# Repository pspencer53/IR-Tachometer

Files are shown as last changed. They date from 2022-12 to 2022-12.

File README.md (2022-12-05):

# IR-Tachometer
This is my learning experience building a very low cost tachometer that I wanted to build to measure the RPM of the spindles of the various CNC Routers that I have been using. 
## Hardware 
- Arduino Mini-Pro ( under $4.00 at [AliExpress](https://www.aliexpress.com/item/32821902128.html) )
These are now obsolete, but any arduino will do.  I just happen to have a few of these
- OLED Display ($3.50 at [AliEpress](https://www.aliexpress.com/item/32920071528.html) (Uses Adafuit SSD1306 library) 
- Infrared Sensor ($2.00 at [AliExpress](https://www.aliexpress.com/item/32952079917.html) ( 3pin IR Infrared barrier Module obstacle avoidance sensor) 
- Lithium Battery Charger Module ($1.00 at [Aliexpress](https://www.aliexpress.com/item/32986135934.html) )
- battery 3.7v 450mAh or so. ($3.65 at [AliExpress](https://www.aliexpress.com/item/4000908332181.html) )
## Design
There are several ways to do this.  I am testing all 3.
1. Count pulses for a period of time using a loop.  This is way too sketchy and was only used as a reference ( [See this article](https://how2electronics.com/digital-tachometer-ir-sensor-arduino/) )
2. Use interupts and measure the time between pulses.  My first attempt at this was less than satsfying.   I added a running average function to smooth out the jitters and it now works pretty well..
3. Use interrupt to time a window and measure how many pulses occur during this window of time, such as 500msec or 1 sec. [See Blinky with Timer1 OVF](https://blog.podkalicki.com/arduino-blinky-with-timer1-ovf/)
4. Use a Frequency Count library such as from [PJRC for the Teensy](https://www.pjrc.com/teensy/td_libs_FreqCount.html)

## Final Code
I implemented option 2, which handles lower RPM's pretty well.  
Essentially, the program sets up an interrupt to trip every time there is a pulse on the sensor, and measures the time since the last pules.  
The RPM is calculated using the width of the pulse.  A 1 Second pulse as an example would be 60 RPM.   10mSec would be 6000 RPM. 

I also implemented a "No Pulses detected" and "Too Close" based on the sensor being either always on or always off.  

The correct operation is when the LED on the sensor is flickering.  

## Help
 - [Github-flavored Markdown info page.](http://github.github.com/github-flavored-markdown/)
 - [Mermaid diagrams](https://mermaid-js.github.io/mermaid/#/)

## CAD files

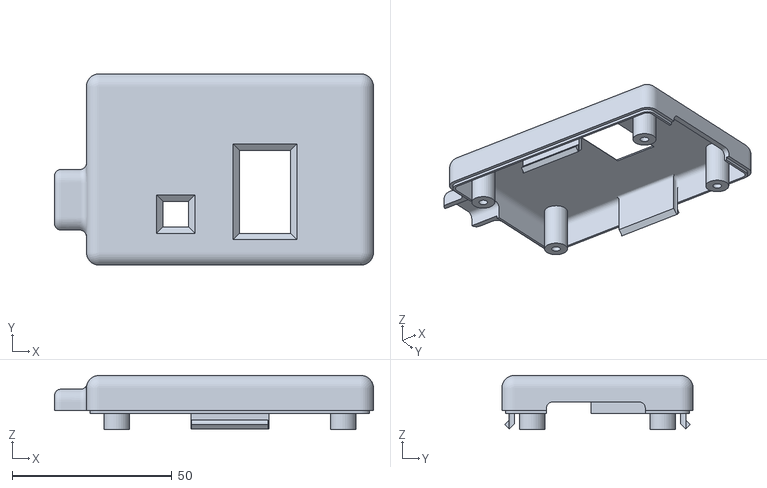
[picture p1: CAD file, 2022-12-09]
Case_Top.stl
100.0 x 60.0 x 17.0

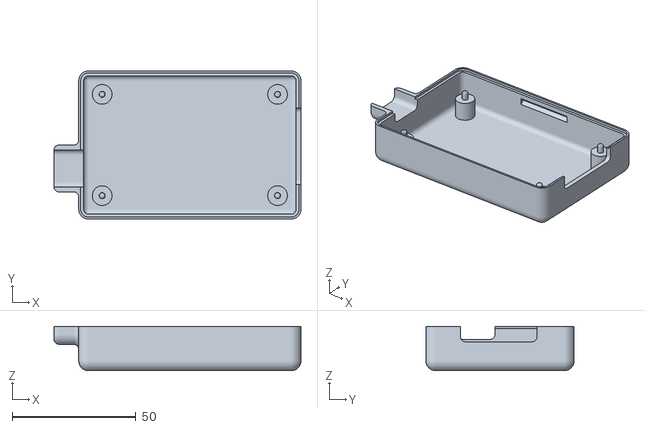
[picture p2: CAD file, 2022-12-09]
Case_Bottom.stl
100.0 x 60.0 x 18.0

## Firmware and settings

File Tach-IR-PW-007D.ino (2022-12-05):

/*********
  12/09/2021: PDS - Configure Tachometer by picking items from DIY Tach script
  12/30/2021: PDS - Updated to use Sensor as a select switch.  Hold finger over sensor while powering on triggers a debug menu. 
                  - Also, turn off Serial unless a menu (above) has been triggered. 
  12/01/2022: PDS - Version 7C.  Uses pulse width.  Can handle very slow pulses as well as fast.
                  - Added setTextColor(WHITE,BLACK) instead if just WHITE
                  - Added a "erase a rectangle" to clear old messages below readings
                  - *DONE* TODO: Verify that the tach is calculating correctly (x/factor?)
                  - Add an averaging function to smooth out the RPM jumping around. 
                     ( https://www.aranacorp.com/en/implementation-of-the-moving-average-in-arduino/ )
                    Added a *RAW* debug line below the smooth RPM text
                  - It is a wrap.
*********/

#include <SPI.h>
#include <Wire.h>
#include <Adafruit_GFX.h>
#include <Adafruit_SSD1306.h>

#define SCREEN_WIDTH 128 // OLED display width, in pixels
#define SCREEN_HEIGHT 64 // OLED display height, in pixels
#define SENSORPIN 2 // Sensor IO Pin

// Declaration for an SSD1306 display connected to I2C (SDA, SCL pins)
#define OLED_RESET     -1 // Reset pin # (or -1 if sharing Arduino reset pin)
Adafruit_SSD1306 display(SCREEN_WIDTH, SCREEN_HEIGHT, &Wire, OLED_RESET);

// Define Variables
char strCodeName[] = "Tach-OLED";
char strCodeVersion[] = "7.3";
unsigned long rpmtime;
float rpmfloat;
unsigned int rpm;
bool tooslow = 1;
int valSensorPin;

  // Running Average
  const int numReadings  = 10;
  int readings [numReadings];
  int readIndex  = 0;
  long total  = 0;

void setup() {
  // Sensor Pin Enable
  pinMode(SENSORPIN, INPUT);

  // Check to see if the sensor is being "pressed" for debug mode:
  valSensorPin = digitalRead(SENSORPIN);   // read the input pin

  Serial.begin(115200);
  while (!Serial) {
    ; // wait for serial port to connect. Needed for native USB
  }
  // Serial Print Program Name and Version
  Serial.print(strCodeName); 
  Serial.print(" "); 
  Serial.println(strCodeVersion);
  if ( valSensorPin == 1) {
    Serial.println("SenserPin HIGH ...");
  }
  
  // Set up Interupt Timers
  TCCR1A = 0; //Initialize Timer "A"
  TCCR1B = 0; //Initialize Timer "B"
  TCCR1B |= (1 << CS12); //Prescaler 256
  TIMSK1 |= (1 << TOIE1); //enable timer overflow

  // SSD1306_SWITCHCAPVCC = generate display voltage from 3.3V internally
  if(!display.begin(SSD1306_SWITCHCAPVCC, 0x3C)) { 
    Serial.println(F("SSD1306 allocation failed"));
  }

  // Setup Display
  display.clearDisplay();
  display.setTextSize(1);
  display.setTextColor(WHITE,BLACK);
  display.setCursor(0, 0); // X*Y Graphical location (128x64)
  display.print(strCodeName);
  display.print(" ");
  display.println(strCodeVersion);
  if ( valSensorPin == 0) {
    display.println("DEBUG MODE");
  } else {
    display.println("Slow MODE");
  }
  display.display(); 

  display.setTextSize(2);
  display.setCursor(0, 24); // Gra
  display.println(TCNT1);
  display.display(); 
  attachInterrupt(0, RPM, FALLING);
}

void loop() {
  // put your main code here, to run repeatedly:
  delay(100);
  if (tooslow == 1) {
    //display.clearDisplay();
    display.setTextSize(2);
    display.setTextColor(WHITE,BLACK);
    display.setCursor(0, 24); 
    valSensorPin = digitalRead(SENSORPIN);   // read the input pin
    if (valSensorPin) {
      //display.drawRect(0, 40, display.width(), display.height()-40, WHITE);
      display.fillRect(0, 40, display.width(), display.height()-40, BLACK);
      display.println("No Pulses");
      display.setTextSize(1);
      display.println("Move closer to a");
      display.println("spinny thingy");
      display.println("until LED is blinking");
      display.setTextSize(2);
    } else {
      display.println("Too close");
      display.fillRect(0, 40, display.width(), display.height()-40, BLACK);
      display.setTextSize(1);
      //display.setTextColor(WHITE,BLACK);
      display.setCursor(0,40); 
      display.print("Move Back");
      //display.setTextSize(2);
    }
    display.display(); 
  } else {
    rpmfloat = 120 / (rpmtime/ 31250.00);
    //rpmfloat = 120 / (rpmtime/ 15000.00);
    rpm = round(rpmfloat);
    display.setTextSize(1);
    display.setTextColor(WHITE,BLACK);
    display.fillRect(0, 40, display.width(), display.height()-16, BLACK);
    display.setCursor(0, 48); 
    display.print(rpm);
    display.println(" RPM (raw)");
    rpm = smooth(rpm);
    //display.clearDisplay();
    display.setTextSize(2);
    display.setTextColor(WHITE,BLACK);
    display.fillRect(10, 24, display.width()-10, 16, BLACK);
    display.setCursor(0, 24); 
    display.print(rpm);
    display.println(" RPM");
    display.display(); 
  }
}

// Interrupt Service Routine
ISR(TIMER1_OVF_vect) {
  tooslow = 1;
}
                                         
// Interrupt Timer 
void RPM() {
  rpmtime = TCNT1;
    //if ( valSensorPin == 1) {
      Serial.print("Pulse Width=");
      Serial.println(rpmtime);
    //}
  TCNT1 = 0;
  tooslow = 0;
}

unsigned int smooth(unsigned int newrpm ) { /* function smooth */
  ////Perform average on sensor readings
  unsigned int average;
  // subtract the last reading:
  total = total - readings[readIndex];
  // read the sensor:
  readings[readIndex] = newrpm;
  // add value to total:
  total = total + readings[readIndex];
  // handle index
  readIndex = readIndex + 1;
  if (readIndex >= numReadings) {
    readIndex = 0;
  }
  // calculate the average:
  average = total / numReadings;

  return average;
}

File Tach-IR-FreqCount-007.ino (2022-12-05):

/*********
  12/04/2022: Version 6 of using Interrupts and an optical sensor
              Started over using a COMPA Timer to give a consistent windows of time to count pulses.
              Theory of operation:  Use an interupt to create a heartbeat of consistent time. (eg 1 Sec or 500mSec)
                                    Then count how many pulses occur during that tieme window. 
  12/04/2022: Development:  Built a prototype using a 128x64 OLED display, an IR Obstical avoidance sensor.
  12/04/2022: Added FreqCount library (V1.3.0)
*********/

#include <SPI.h>
#include <Wire.h>
#include <Adafruit_GFX.h>
#include <Adafruit_SSD1306.h>
#include <FreqCount.h>

#define SCREEN_WIDTH 128 // OLED display width, in pixels
#define SCREEN_HEIGHT 64 // OLED display height, in pixels
#define SENSORPIN 2 // Sensor IO Pin

// Declaration for an SSD1306 display connected to I2C (SDA, SCL pins)
#define OLED_RESET     -1 // Reset pin # (or -1 if sharing Arduino reset pin)
Adafruit_SSD1306 display(SCREEN_WIDTH, SCREEN_HEIGHT, &Wire, OLED_RESET);

// Define Variables
char strCodeName[] = "Tach-006";
char strCodeVersion[] = "1.1";
unsigned long rpmtime;
float rpmfloat;
unsigned int rpm;
int valSensorPin;
bool tooslow = 1;
bool debugmode = 0;
bool rpmfastmode = 1;

#define LED_PIN     (13)

void enableints() {
  FreqCount.end(); // Disable FreqCount 

  // Set up Interupt Timers
  TCCR1A = 0; //Initialize Timer "A"
  TCCR1B = 0; //Initialize Timer "B"
  TCCR1B |= (1 << CS12); //Prescaler 256
  TIMSK1 |= (1 << TOIE1); //enable timer overflow
 
}

// Interrupt Service Routine
ISR(TIMER1_OVF_vect) {
  tooslow = 1;
}
                                         
// Interrupt Timer 
void RPM() {
  rpmtime = TCNT1;
    if ( valSensorPin == 1) {
      Serial.println(rpmtime);
    }
  TCNT1 = 0;
  tooslow = 0;
}

void setup() {
  // Setup to read Sensor
  pinMode(SENSORPIN, INPUT);
  
  // setup for Monitor
  Serial.begin(115200);
  while (!Serial) {
    ; // wait for serial port to connect. Needed for native USB
  }

  // Serial Print Program Name and Version
  Serial.print(strCodeName); 
  Serial.print(" "); 
  Serial.println(strCodeVersion);
  
  // Sensor Pin Enable
  pinMode(SENSORPIN, INPUT);

  // Check to see if the sensor is being "pressed" for debug mode:
  valSensorPin = digitalRead(SENSORPIN);   // read the input pin
  if ( valSensorPin == 0) {
    debugmode = 1;
  }
  // Enable OLED Display
  if(!display.begin(SSD1306_SWITCHCAPVCC, 0x3C)) { 
    Serial.println(F("SSD1306 allocation failed"));
    for(;;); // Don't proceed, loop forever
  }
  // Clear the buffer
  // Display Text (V-Large)
  display.clearDisplay();
  display.setTextSize(1);
  display.setTextColor(WHITE,BLACK);
  display.setCursor(0, 0); // X*Y Graphical location (128x64)
  display.print(strCodeName);
  display.print(" ");
  display.println(strCodeVersion);
  if ( debugmode) {
    display.println("DEBUG MODE");
  }
  display.display(); 

  if (rpmfastmode) {
    FreqCount.begin(1000); // Initialize setting the gateway interval
  }
}

void loop() {
  if (FreqCount.available()) {
    unsigned long count = FreqCount.read()*60;  // Number of pulses in 1 minute
    Serial.println(count);

    // Set up OLED display
    display.setTextSize(2);
    display.setTextColor(WHITE,BLACK);
    display.setCursor(0, 24);
    display.fillRect(0, 32, display.width(), display.height()-40, WHITE); // Clear line
    // print right justified
    if (count < 9999) { display.print(" "); }
    if (count < 999) { 
      display.print(" "); 
      Serial.print("RPM Too Low.");
      //Serial.println(count);
    }
    if (count < 99) { display.print(" "); }
    if (count < 9) { display.print(" "); }
    display.print(count);
    display.println(" RPM");
    display.display(); 
  }

  // Test if the RPM is too low
//  if (count < 1000) {
//    Serial.print("RPM Too Low.");
//    Serial.println(count);
//  }
}

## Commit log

2022-12-05 IR-TACH using Pulse width.
    Accurate for lower frequencies. (Min=60 RPM, Max ~= 60K RPM) Added a "Smooth" function to normalize erratic input.
2022-12-05 Tach Using FreqCount Library
    More accurate at higher frequencies, Unable to measure lower than about 600 RPM.
2022-12-05 IR-Tach using Pulse Width
    IR Tach using Pulse Width interrupts. Does well with lower frequencies. Calculates the RPM using the time between pulses. Maxes out at 65535 RPM. Min is about 60 RPM
2022-12-05 Update Tach-IR-PW-007D.ino
    Fixed minor bug with display updates.
    [Tach-IR-PW-007D.ino]
2022-12-09 Added Case 3D print files
    [Case_Bottom.stl, Case_Top.stl]
2022-12-09 KiCAD Files
    Created KiCAD files with Schematic
